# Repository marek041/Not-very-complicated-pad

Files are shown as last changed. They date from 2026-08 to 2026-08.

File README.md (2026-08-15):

# Not-very-complicated-pad
simple macro pad. 6 keys with oled display and Xiao RP2040. Macro pad for simple tasks like ctrl+c, ctrl+v, etc. also programs opening with windows search and shutdown button :O

## Features: 
- 6 keys
- 128x32 oled display
- 3 leds
- pretty silkcreen art
- cool case :)

## Cad design:
  This includes 3d printed case of 3 parts, everything is connected with M3 bolts screwed in plastic.
  
  It was made in Fusion360 and components imported from KiCad
  (i added step files so it could generate full PCB with components )

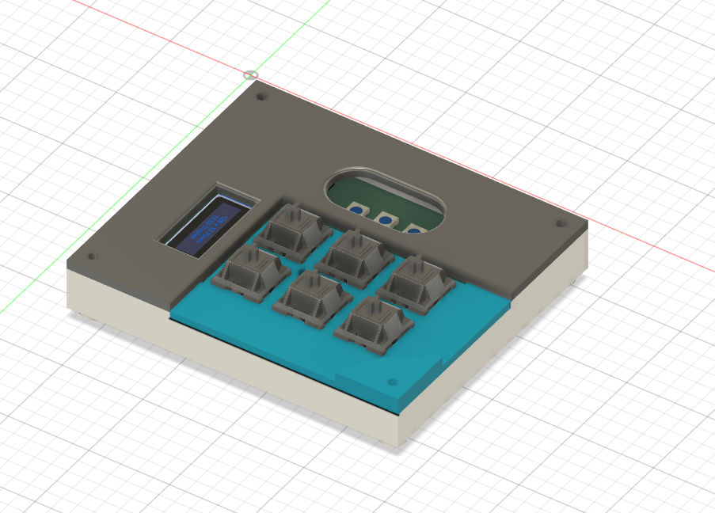
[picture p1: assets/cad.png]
  

  it is all in cad folder

## PCB:
PCB i made in KiCad 

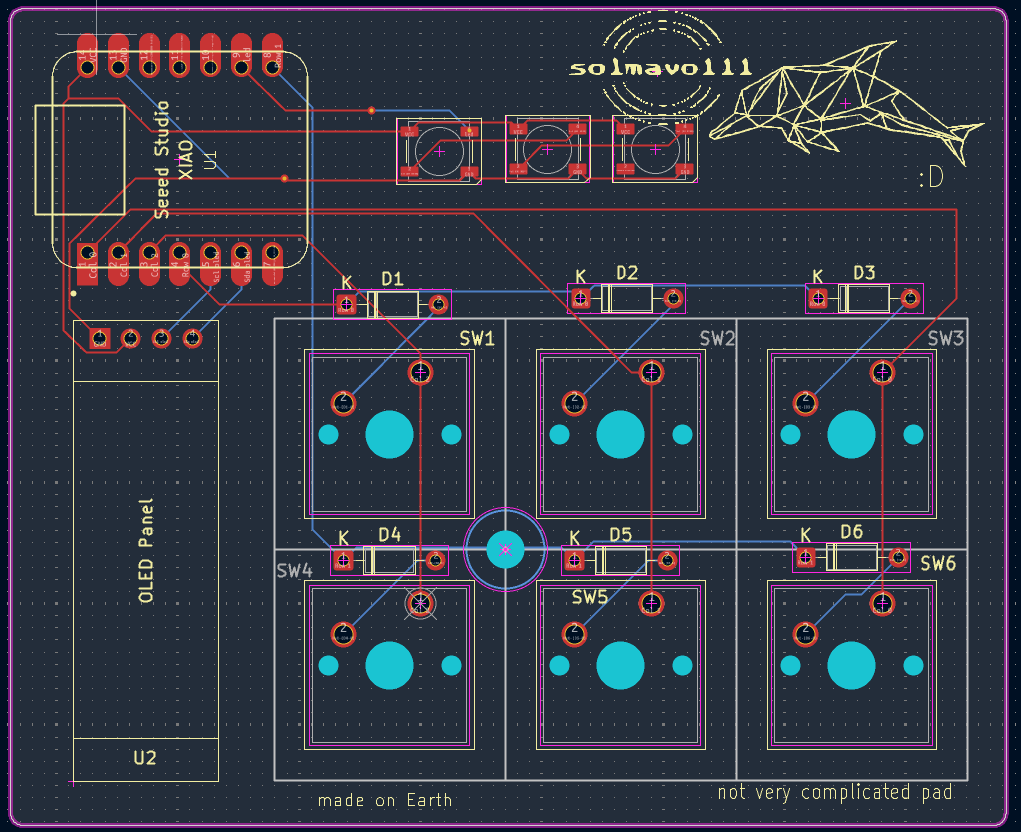
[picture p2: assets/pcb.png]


and Schematic 

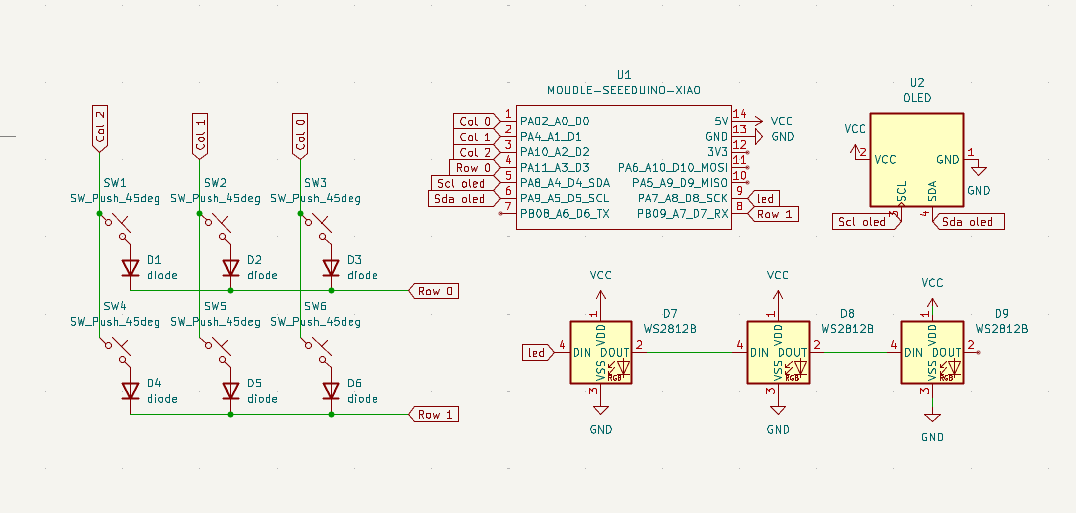
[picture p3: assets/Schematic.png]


## BOM:
  All components right there:

   - 6x Cheery MX switches
   - 6x DSA keycaps
   - 4x M3x16mm SHCS bolts
   - 6x 1N4148 DO-35 diodes
   - 3x WS28128 LEDs
   - 1x 0.91" 128x32 OLED Display
   - 1x XIAO RP2040
   - Case (3 printed parts)
 
## EXTRA stuff
This is my first project on Hack Club and also first time designing PCB
:D

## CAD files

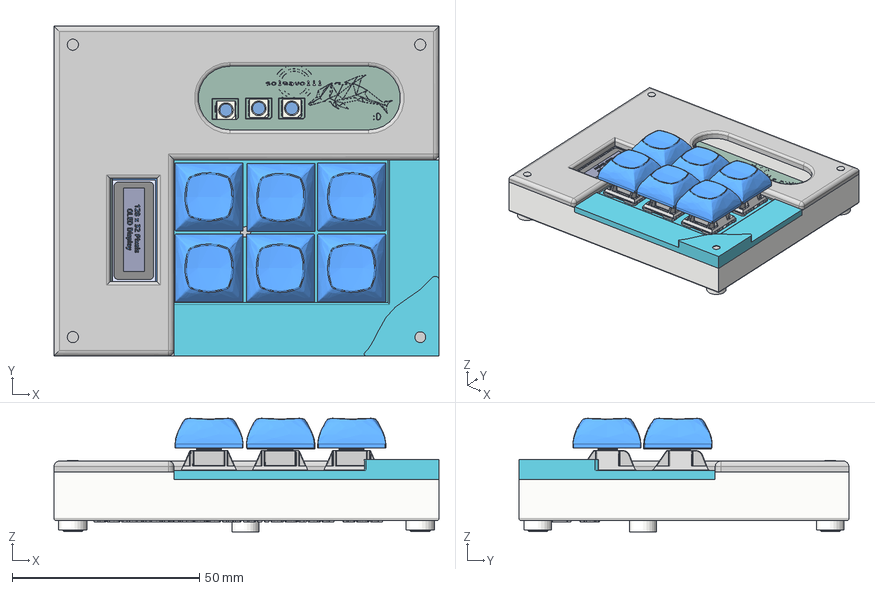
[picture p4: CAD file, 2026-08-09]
cad/Not_very_complicated_pad.step
102.8 x 88.1 x 30.3 mm
D_DO-35_SOD27_P7.62mm_Horizontal_1 x 6
type-c v2
smd_button v3
DOUT
DIN
VSS
VDD
smd_button v3(Mirror)
LED_WS2812B_PLCC4_50x50mm_P32mm x 3
Board_001
1x4 Male Header_001
0603 Capacitor_001
0603 Capacitor_002
0603 Capacitor_003
0603 Capacitor_004
0603 Capacitor_005
0603 Capacitor_006
0603 Capacitor_007
0603 Capacitor_008
0603 Resistor_001
0603 Resistor_002
0603 Resistor_003
0603 Resistor_004
0603 Resistor_005
Surface Mount Transistor_001
MX_DOWN x 6
MX_UP x 6
UP_MX x 6
MX_PIN x 6
MX_SPRING x 6
MX_CLICK x 6
NotF657_PCB

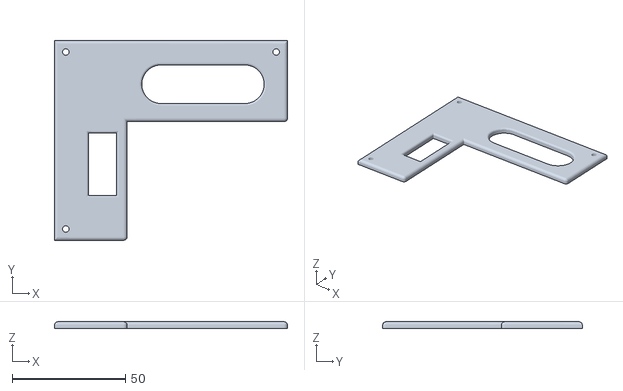
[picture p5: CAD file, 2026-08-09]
production/Top case part1.stl
102.8 x 88.1 x 2.90

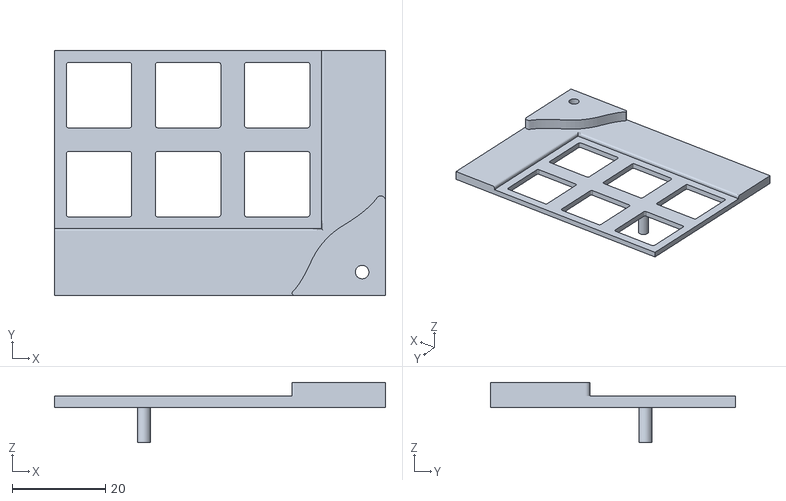
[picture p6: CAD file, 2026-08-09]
production/top case part2.stl
70.8 x 52.4 x 12.9

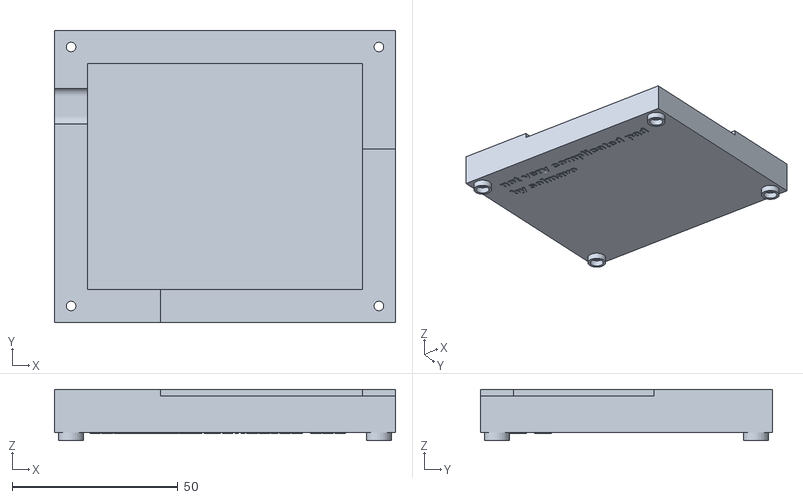
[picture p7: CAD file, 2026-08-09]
production/bottom case .stl
102.8 x 88.1 x 15.5

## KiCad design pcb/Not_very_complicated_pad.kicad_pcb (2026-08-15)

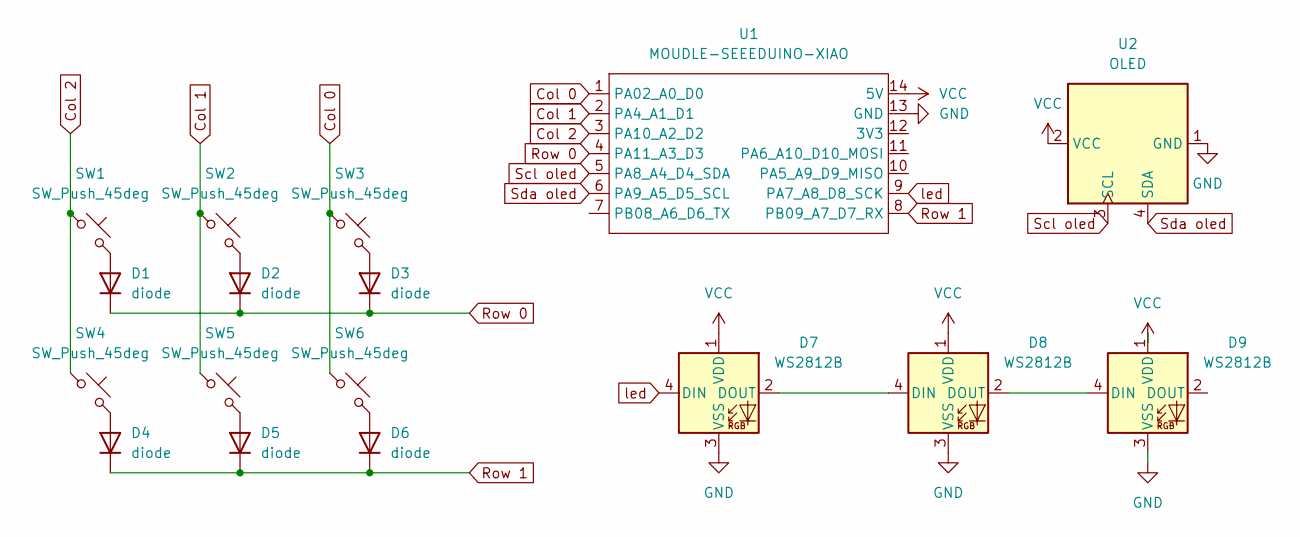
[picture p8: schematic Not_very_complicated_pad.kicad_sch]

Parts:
D1, D2, D3, D4, D5, D6: diode; D_DO-35_SOD27_P7.62mm_Horizontal
D7, D8, D9: WS2812B; LED_WS2812B_PLCC4_5.0x5.0mm_P3.2mm
SW1, SW2, SW3, SW4, SW5, SW6: SW_Push_45deg; SW_Cherry_MX_1.00u_PCB
U1: MOUDLE-SEEEDUINO-XIAO; XIAO-Generic-Hybrid-14P-2.54-21X17.8MM
U2: OLED; SSD1306-0.91-OLED-4pin-128x32

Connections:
Col 0: SW3.1, SW6.1, U1.1 (PA02_A0_D0)
Col 1: SW2.1, SW5.1, U1.2 (PA4_A1_D1)
Col 2: SW1.1, SW4.1, U1.3 (PA10_A2_D2)
GND: D7.3 (VSS), D8.3 (VSS), D9.3 (VSS), U1.13 (GND), U2.1 (GND)
unnamed: D1.2 (A), SW1.2
unnamed: D2.2 (A), SW2.2
unnamed: D3.2 (A), SW3.2
unnamed: D4.2 (A), SW4.2
unnamed: D5.2 (A), SW5.2
unnamed: D6.2 (A), SW6.2
unnamed: D7.2 (DOUT), D8.4 (DIN)
unnamed: D8.2 (DOUT), D9.4 (DIN)
Row 0: D1.1 (K), D2.1 (K), D3.1 (K), U1.4 (PA11_A3_D3)
Row 1: D4.1 (K), D5.1 (K), D6.1 (K), U1.8 (PB09_A7_D7_RX)
Scl oled: U1.5 (PA8_A4_D4_SDA), U2.3 (SCL)
Sda oled: U1.6 (PA9_A5_D5_SCL), U2.4 (SDA)
VCC: D7.1 (VDD), D8.1 (VDD), D9.1 (VDD), U1.14 (5V), U2.2 (VCC)
led: D7.4 (DIN), U1.9 (PA7_A8_D8_SCK)

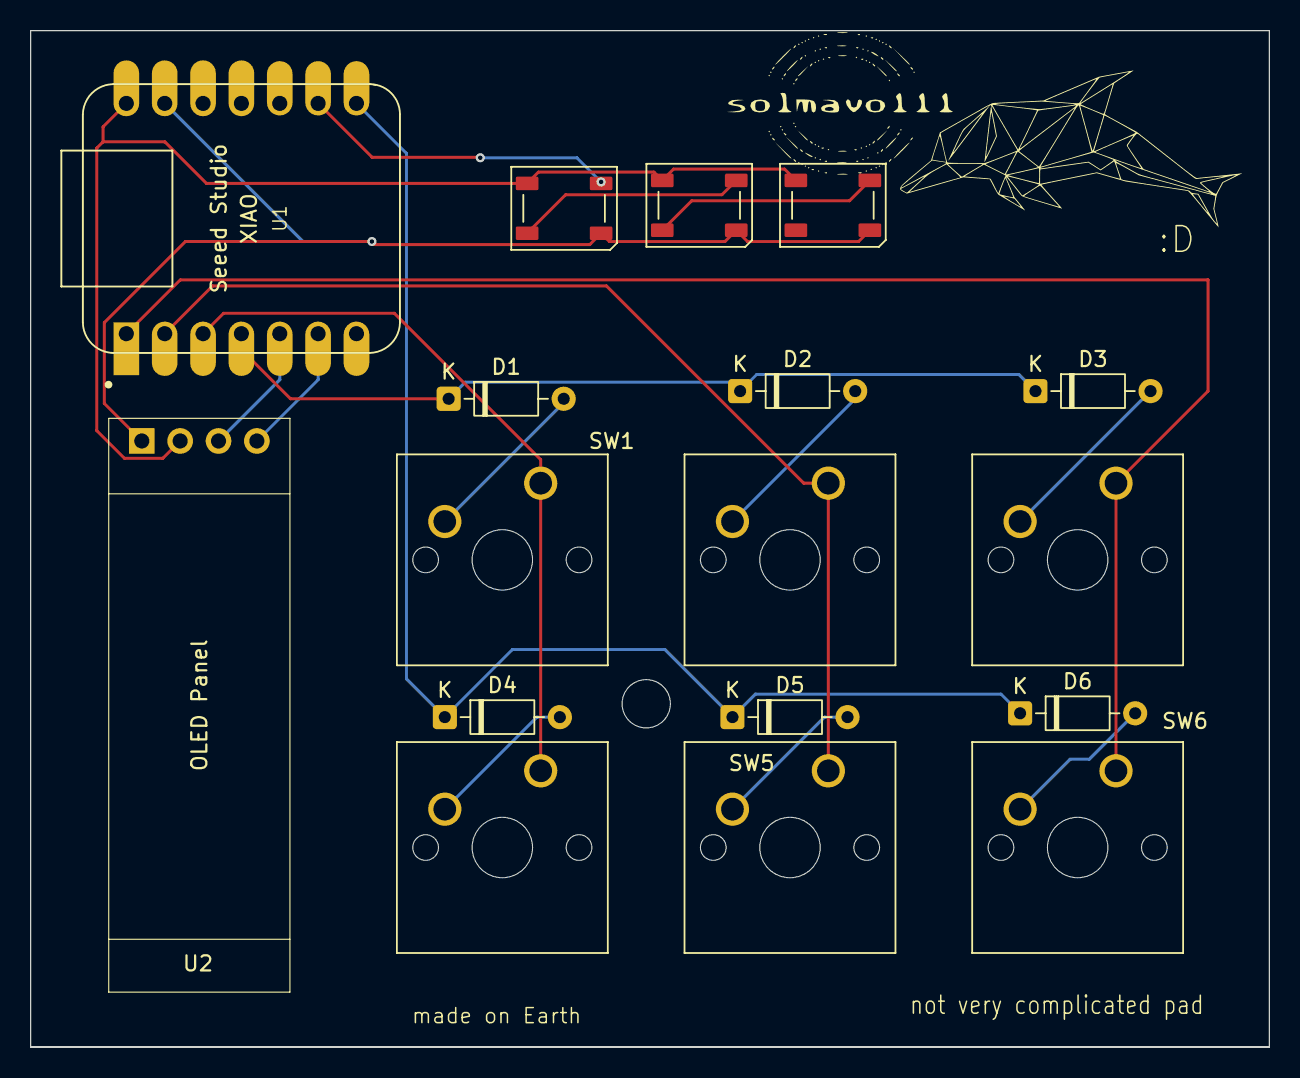
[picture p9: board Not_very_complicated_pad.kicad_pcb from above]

Board: 2 copper layers, 82.0 x 67.3 mm, 17 parts (0 on the bottom side), 18 nets.

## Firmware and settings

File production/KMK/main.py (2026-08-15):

from kb import keyboard
from kmk.keys import KC, LCTL
from kmk.modules.macros import Macros, Delay, Tap

macros = Macros()
keyboard.modules.append(macros)

# Windows Force Shutdown Macro
OFF = KC.MACRO(
    KC.LGUI(KC.R),
    Delay(400),
    "shutdown /s /f /t 0",
    Delay(200),
    Tap(KC.ENTER),
)

FUSION = KC.MACRO(
    Tap(KC.LGUI),
    Delay(200),
    "fusion",
    Delay(200),
    Tap(KC.ENTER),
)

buds = KC.MACRO(
    Tap(KC.LGUI),
    Delay(200),
    "galaxy buds",
    Delay(200),
    Tap(KC.ENTER),
)

send = KC.MACRO(
    Tap(KC.LGUI),
    Delay(200),
    "LocalSend",
    Delay(200),
    Tap(KC.ENTER),
)

keyboard.keymap = [
    [OFF,   LCTL(KC.V), LCTL(KC.C)],
    [send,  buds,       FUSION],
]

if __name__ == '__main__':
    keyboard.go()

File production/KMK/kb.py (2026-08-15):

import board
import busio

from kmk.kmk_keyboard import KMKKeyboard
from kmk.scanners import DiodeOrientation
from kmk.extensions.display import Display, TextEntry
from kmk.extensions.display.ssd1306 import SSD1306
from kmk.extensions.rgb import RGB, AnimationModes

COL0 = board.D0
COL1 = board.D1
COL2 = board.D2
ROW0 = board.D3
ROW1 = board.D7

LED_PIN = board.D8 


bus = busio.I2C(scl=board.D5, sda=board.D4)

driver = SSD1306(i2c=bus, device_address=0x3C)

display = Display(
    display=driver,
    entries=[
        TextEntry(text='Hello', x=64, y=0, x_anchor="M", scale=2)
    ],
    width=128,
    height=64,
    dim_time=10,
    dim_target=0.2,
    off_time=1200,
    brightness=0.9
)

keyboard = KMKKeyboard()
keyboard.extensions.append(display)

rgb = RGB(
    pixel_pin=LED_PIN,
    num_pixels=3,
    animation_mode=AnimationModes.BREATHING,
    val_limit=150,
)
keyboard.extensions.append(rgb)

keyboard.col_pins = (COL0, COL1, COL2)
keyboard.row_pins = (ROW0, ROW1)
keyboard.diode_orientation = DiodeOrientation.COL2ROW

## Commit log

2026-08-09 Create cad
2026-08-09 Add missing newline at end of cad file
2026-08-09 Rename Screenshot 2026-08-07 183954.png to cad.png
2026-08-09 Rename Screenshot 2026-08-08 145008.png to cad.png
2026-08-09 Enhance README with features and CAD design details
    Updated README with more detailed feature descriptions and added CAD design section.
2026-08-09 Rename Screenshot 2026-08-09 195313.png to pcb.png
2026-08-09 Rename Screenshot 2026-08-09 195427.png to Schematic.png
2026-08-09 Enhance README with project details and images
    Updated README with additional details on CAD design, PCB, BOM, and extra project information.
2026-08-15 Rename Top case 1.stl to Top case part1.stl
    [Top case part1.stl]
2026-08-15 Rename top case 2.stl to top case part2.stl
    [top case part2.stl]
2026-08-15 Fix formatting issues in BOM.md
2026-08-15 Add BOM.md with list of required parts
